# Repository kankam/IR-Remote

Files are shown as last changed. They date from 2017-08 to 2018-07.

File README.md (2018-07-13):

# IR-Remote
This project is to build an IR Remote for Sony Nex 5N Camera. 

An Arduino Pro Mini is used as the Control Unit.
A PCB is designed to mount all the components together.
A plastic case is also designed and can be printed by 3d printers.

The arduino code use the multiCameraControl Libary by Sebastian Setz. Applause to him.

	Project....:  http://sebastian.setz.name/arduino/my-libraries/multi-Camera-IR-Control
	Contact....:  http://Sebastian.Setz.name
	
Theoretically, all camera models include in multiCameraControl Libary (i.e. canon, nikon, olympus, minolta, sony, pentax,) should also be supported by this project with making slight modifications in the Arduino code. 
However, no test has been done except on the Sony Nex 5N Camera.

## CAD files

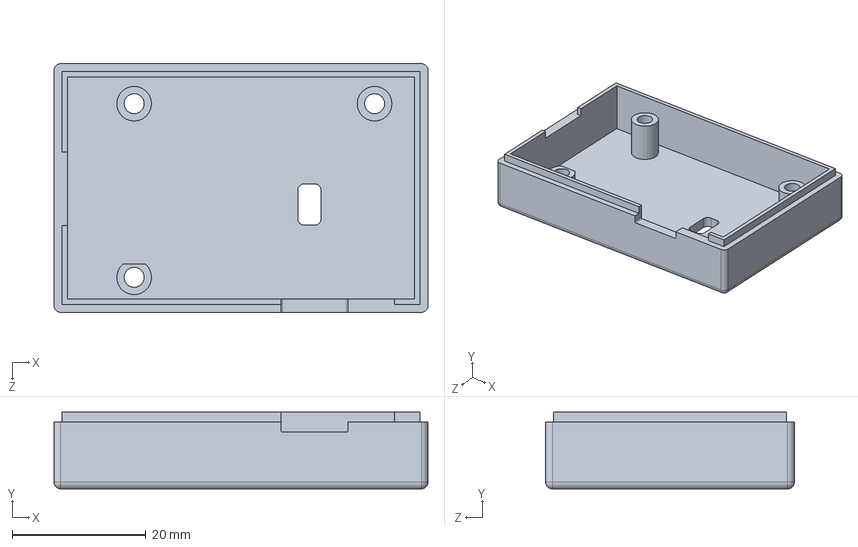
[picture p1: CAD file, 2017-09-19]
SolidWorks/Ir_box_base.SLDPRT
56.0 x 11.5 x 37.2 mm

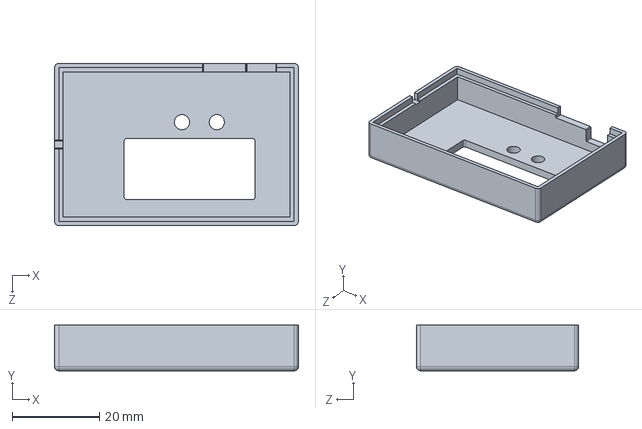
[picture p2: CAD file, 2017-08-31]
SolidWorks/Ir_box_top_without_powerplug.SLDPRT
56.0 x 10.5 x 37.2 mm

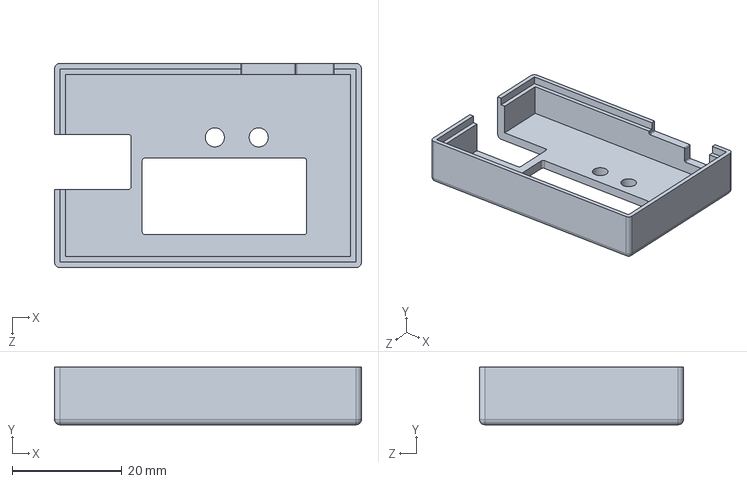
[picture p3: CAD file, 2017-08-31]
SolidWorks/Ir_box_top.SLDPRT
56.0 x 10.5 x 37.2 mm

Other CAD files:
stl/Ir_box_base.STL
stl/Ir_box_top.STL
stl/Ir_box_top_without_powerplug.STL

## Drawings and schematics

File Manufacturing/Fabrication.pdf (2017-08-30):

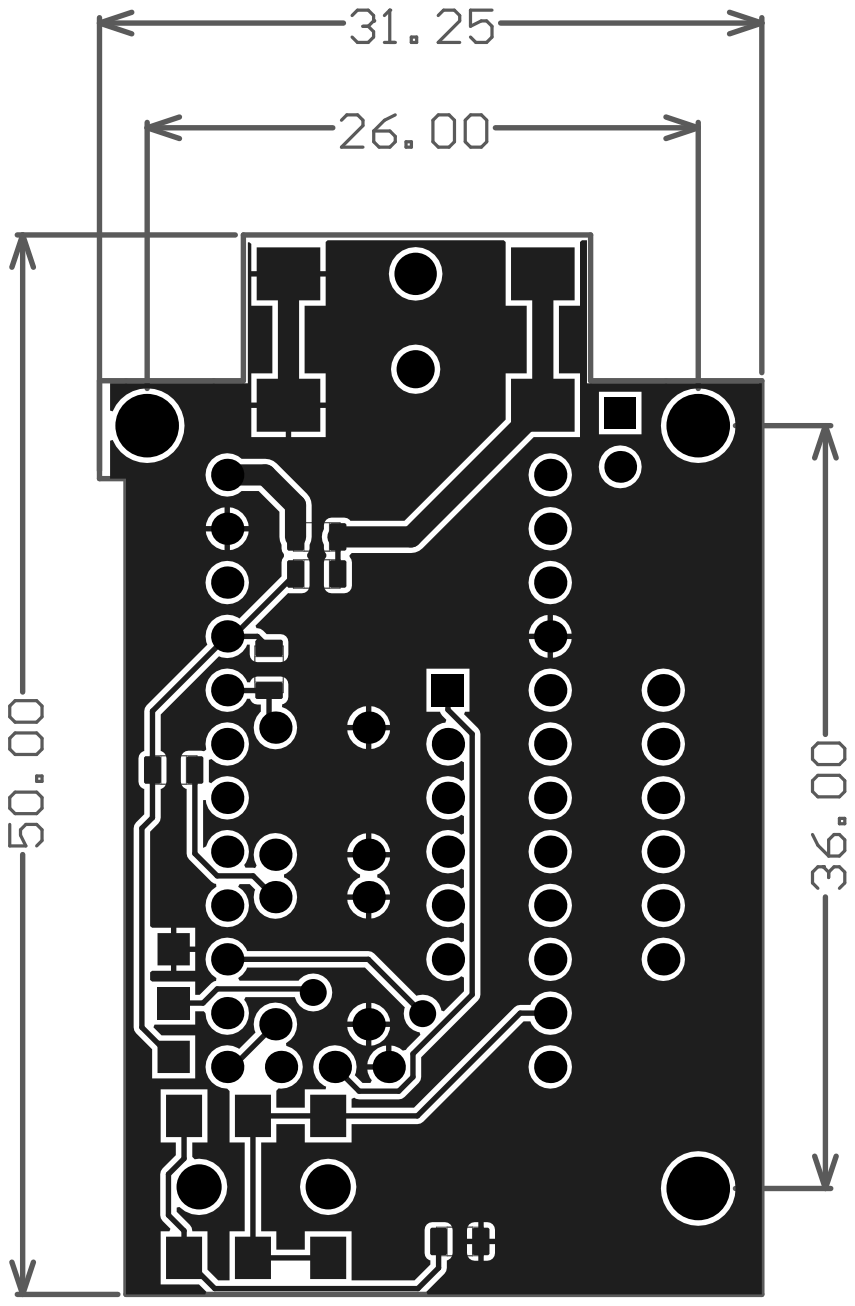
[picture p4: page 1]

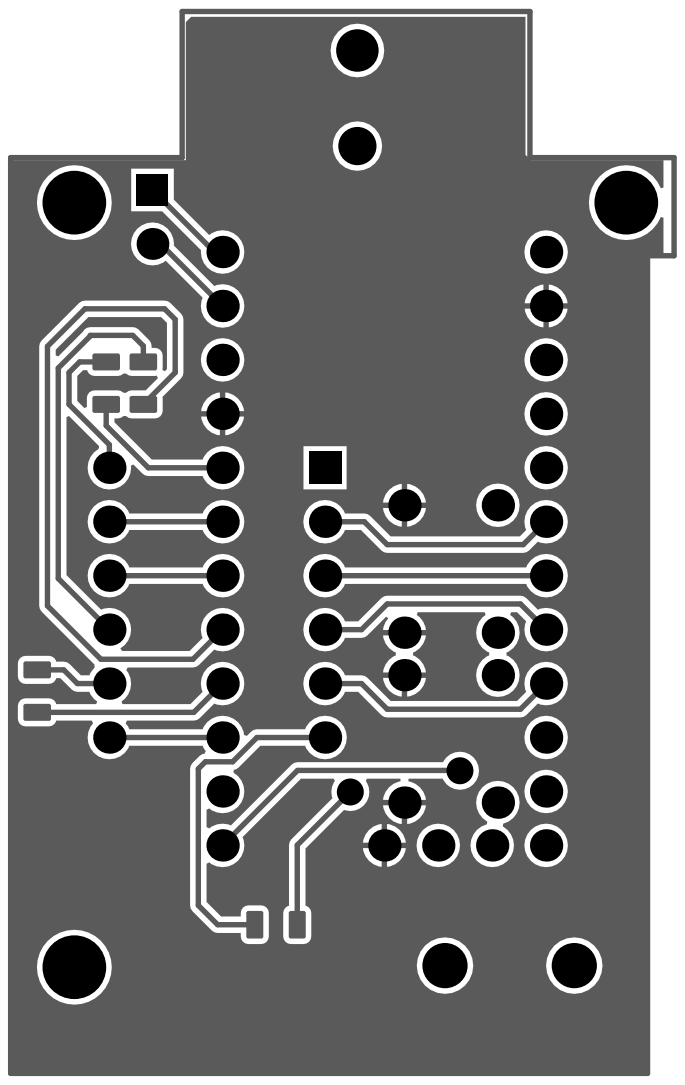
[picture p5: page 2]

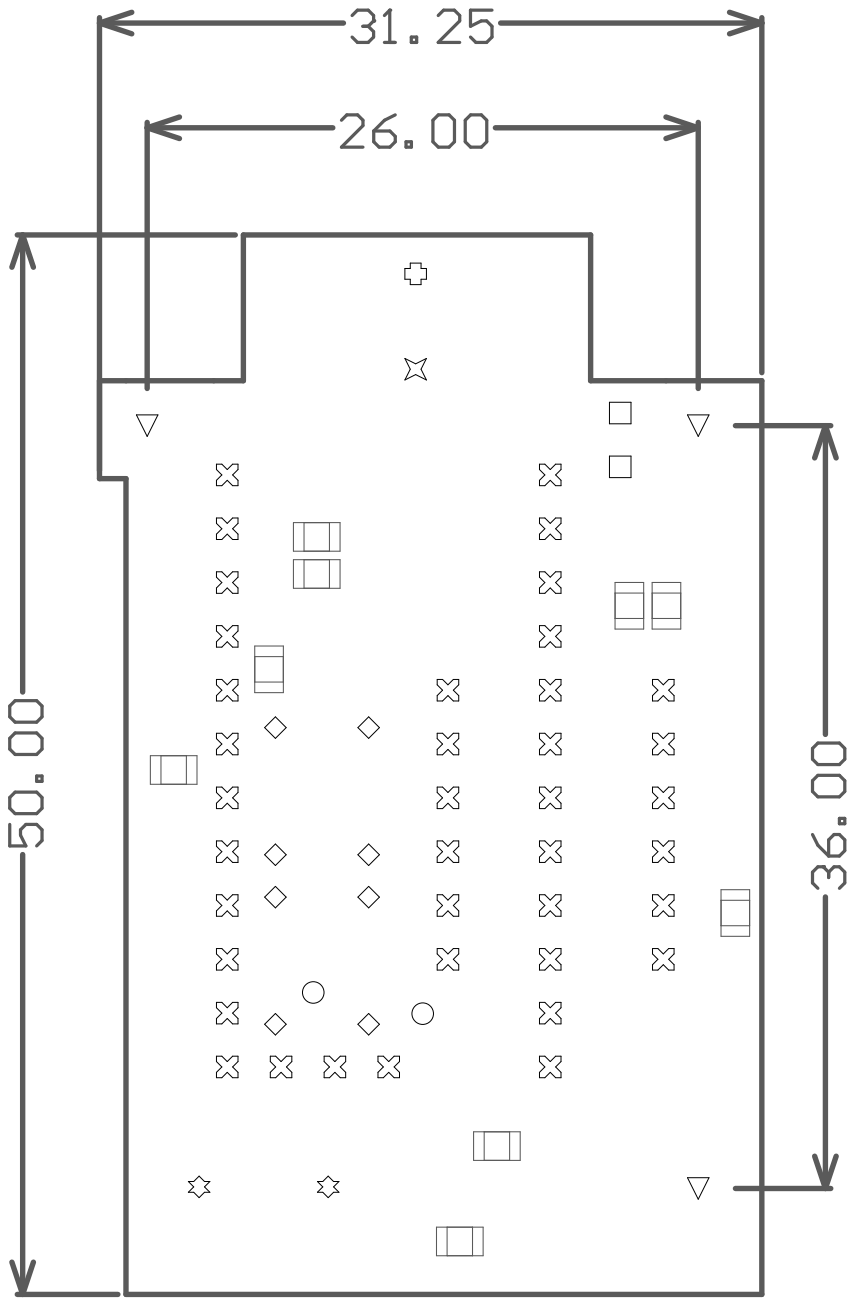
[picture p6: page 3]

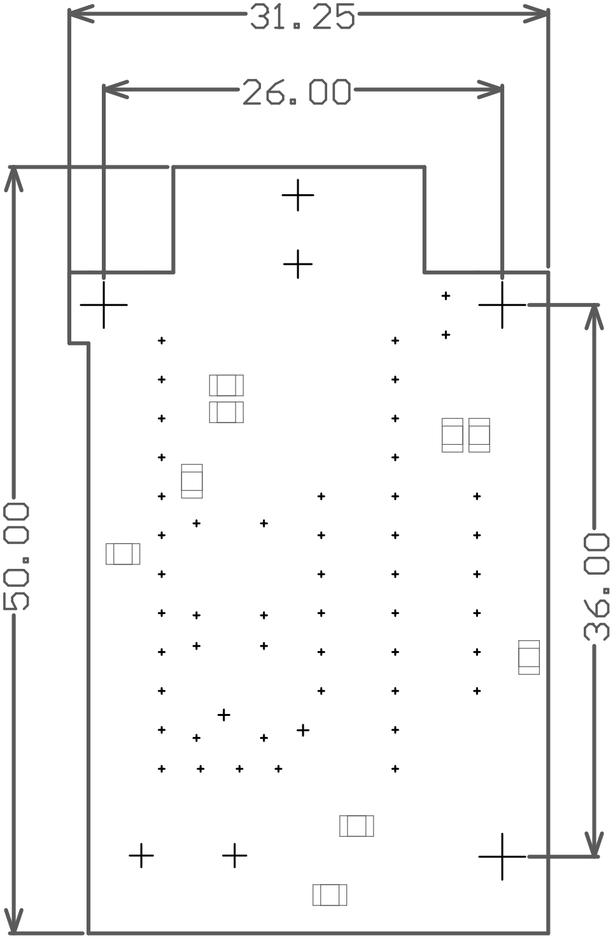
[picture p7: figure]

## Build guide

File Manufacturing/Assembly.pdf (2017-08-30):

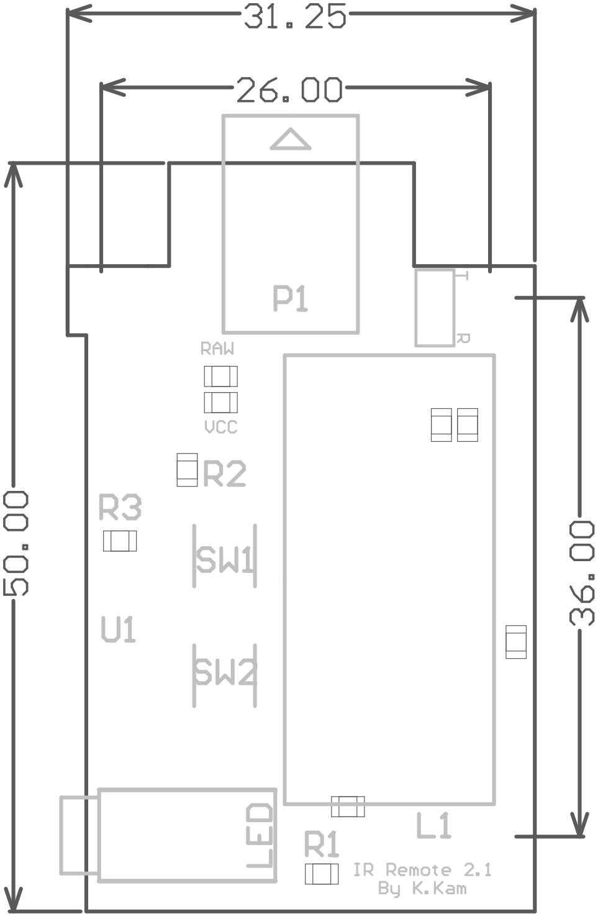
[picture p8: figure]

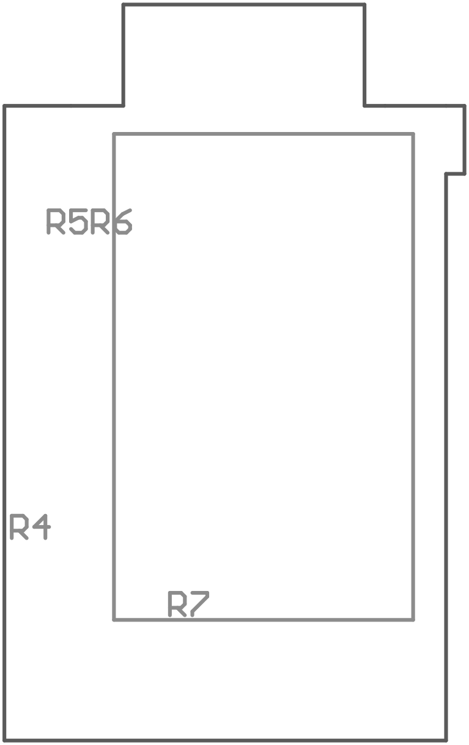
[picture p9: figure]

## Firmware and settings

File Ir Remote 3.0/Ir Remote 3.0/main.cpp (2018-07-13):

/*
 * Ir Remote 3.0.cpp
 *
 * Created: 7/8/2018 11:06:00 PM
 * Author : KanKam
 */ 

#include "main.h"
#include <avr/io.h>
#include <avr/interrupt.h>
#include <util/atomic.h>
#include <util/delay.h>




const char *digPin[4] = {digPin1, digPin2, digPin3, digPin4};
const char *LEDPin[7] = {LEDPinA, LEDPinB, LEDPinC, LEDPinD, LEDPinE, LEDPinF, LEDPinG};
const char *LedPin = irLed;
    
uint16_t counter = 5;    //Default counter is set to 5
uint16_t Digit = 0;      //Display Digit
uint16_t shot = 0;       //Shot count
uint64_t lastCount = 0;  //Time stamp for timing

void digitalWrite(const char *port, bool state){
    //Just like the Arduino,Yeah~!
    int pin =  port[1] - '0';
    if(state == 1)
    {
        switch (port[0]){
            case 'B':
            PORTB |= (1<<pin);
            break;
            case 'C':
            PORTC |= (1<<pin);
            break;
            case 'D':
            PORTD |= (1<<pin);
            break;
            }
        }else{
            switch (port[0]){
                case 'B':
                PORTB &= ~(1<<pin);
                break;
                case 'C':
                PORTC &= ~(1<<pin);
                break;
                case 'D':
                PORTD &= ~(1<<pin);
                break;
                }
        }
}

void shutterNow(void){
    //Ir signal output for Sony camera
    //Source(Author): http://sebastian.setz.name/arduino/my-libraries/multiCameraIrControl (Sebastian Setz)
    bool _seq[] = {1,0,1,1,0,1,0,0,1,0,1,1,1,0,0,0,1,1,1,1}; 
    for (uint8_t j = 0; j < 3; j++) {
        //_freq = 40;
        //pause = 8;
        //high(2320,_freq,_pin);
        for (uint8_t i = 0; i < 145; i++){
            digitalWrite(LedPin,1);
            _delay_us(8);
            digitalWrite(LedPin,0);
            _delay_us(8);
        }
        _delay_us(650);
        for (uint8_t i = 0; i < sizeof(_seq); i++){
            if (_seq[i]==0){
                //high(575,_freq,_pin);
                for (uint8_t i = 0; i < 35; i++){
                    digitalWrite(LedPin,1);
                    _delay_us(8);
                    digitalWrite(LedPin,0);
                    _delay_us(8);
                }
                _delay_us(650);
            }
            else{
                //high(1175,_freq,_pin);
                for (uint8_t i = 0; i < 73; i++){
                    digitalWrite(LedPin,1);
                    _delay_us(8);
                    digitalWrite(LedPin,0);
                    _delay_us(8);
                }
                _delay_us(650);
                _delay_us(650);
            }
        }
        _delay_us(10000);
    }
}
    
void DisplaySingleDigit(uint8_t digit){
    {
        //Display Single Digit on 7 segment display
        //Conditions for displaying segment a
        if(digit!=1 && digit != 4)
        digitalWrite(LEDPin[0],1);
            
        //Conditions for displaying segment b
        if(digit != 5 && digit != 6)
        digitalWrite(LEDPin[1],1);
            
        //Conditions for displaying segment c
        if(digit !=2)
        digitalWrite(LEDPin[2],1);
            
        //Conditions for displaying segment d
        if(digit != 1 && digit !=4 && digit !=7)
        digitalWrite(LEDPin[3],1);
            
        //Conditions for displaying segment e
        if(digit == 2 || digit ==6 || digit == 8 || digit==0)
        digitalWrite(LEDPin[4],1);
            
        //Conditions for displaying segment f
        if(digit != 1 && digit !=2 && digit!=3 && digit !=7)
        digitalWrite(LEDPin[5],1);
        //Conditions for displaying segment g
        if (digit!=0 && digit!=1 && digit !=7)
        digitalWrite(LEDPin[6],1);
    }
}
    
void turnOff(void){
    //Clear 7 segment display
    for(uint8_t i = 0; i < 7; i++){
        digitalWrite(LEDPin[i],0);
    }
}

void displayDigit(uint16_t digit){
    //Display a 4 digit number
    uint16_t fourDigit = digit;
    uint8_t InDigit[4] = {0,0,0,0};
        
    for(int8_t i = 3; i > -1 ; i--) {
        //Store a 4 digit number in a array
        if(fourDigit <= 0){
        InDigit[i] = 0;
        }else {
            InDigit[i] = fourDigit % 10;
            fourDigit /= 10;}
    }
    //7 segment display take turns to display their digit respectively
    for (int b=0; b<4; b++){
        turnOff();
        for(int a=0; a<4; a++){
            digitalWrite(digPin[a],1);
        }
        digitalWrite(digPin[b],0);
        DisplaySingleDigit(InDigit[b]);
        _delay_ms(5);        
    }
}
/*
*avr-millis-function 
*https://github.com/monoclecat/avr-millis-function
*/
volatile unsigned long timer1_millis;

ISR(TIMER1_COMPA_vect)
{
    timer1_millis++;
}

void init_millis(unsigned long f_cpu)
{
    unsigned long ctc_match_overflow;
    
    ctc_match_overflow = ((f_cpu / 1000) / 8); //when timer1 is this value, 1ms has passed
    
    // (Set timer to clear when matching ctc_match_overflow) | (Set clock divisor to 8)
    TCCR1B |= (1 << WGM12) | (1 << CS11);
    
    // high byte first, then low byte
    OCR1AH = (ctc_match_overflow >> 8);
    OCR1AL = ctc_match_overflow;
    
    // Enable the compare match interrupt
    TIMSK1 |= (1 << OCIE1A);
    
    //REMEMBER TO ENABLE GLOBAL INTERRUPTS AFTER THIS WITH sei(); !!!
}

unsigned long millis ()
{
    unsigned long millis_return;
    
    // Ensure this cannot be disrupted
    ATOMIC_BLOCK(ATOMIC_FORCEON) {
        millis_return = timer1_millis;
    }
    return millis_return;
}
/*
*
*/

int main(void)
{
    //Set up GPIO
    //Set them all as output and low
    DDRB = 0xFF;
    PORTB = 0x00;
    DDRC = 0xFF;
    PORTC = 0x00;
    DDRD = 0xFF;
    PORTD = 0x00;
    
    //Set up UP/Down buttons
    DDRC &= ~(1 << DDC2);   //PC2
    PORTC |= (1 << PORTC2); // turn On the Pull-up
    DDRC &= ~(1 << DDC3);   //PC3
    PORTC |= (1 << PORTC3); // turn On the Pull-up
    
    //Set up State Switch
    //Set PC1 (PCINT9 pin) as an input with pull-up enabled
    DDRC &= ~(1 << DDC1);          // Clear the PC1 pin    
    PORTC |= (0 << PORTC1);        // turn On the Pull-down
    PCICR |= (1 << PCIE1);         // set PCIE1 to enable PCMSK1 scan
    PCMSK1 |= (1 << PCINT9);       // set PCINT9 to trigger an interrupt on state change
    
    //run setting mode once if boot with modeSwitch set to 1
    uint16_t delay = 500;
    while (PINC & (1<<PINC1)){        
        displayDigit(counter);
        turnOff();
        if ((PINC & (1<<PINC2))){
            if(counter < 9999){
                counter++;
            }
            if(delay>=5){
                //increase rate when long press
                delay = delay*0.8;
            }
            _delay_ms(delay);
        }
        else if ((PINC & (1<<PINC3))){
            if(counter > 0){
                counter--;
            }
            if(delay>=5){
                //increase rate when long press
                delay = delay*0.8;
            }
            _delay_ms(delay);
            }else{
            delay = 500;
        }
    }
    //Turn on millis counter
    init_millis(F_CPU);
    // turn on interrupts
    sei();
    
    while (1){ //main loop
        /*
        *Note to User:
        *The code is decide for the shutter set in bulb mode.
        *Therefore, counter should be set to shutter - 1 second if shutter time on camera is preset.
        */
        lastCount = millis();
        while (millis() < (lastCount + 3000)){
            displayDigit(shot); //Display shot count, buffer time is set to 3s
        }
        shutterNow();//Bulb mode on camera: Open shutter/ Shutter time is preset: Take a photo

        Digit = counter;
        while( Digit > 0){
            lastCount = millis();
            while (millis() < (lastCount + 1000)){
                displayDigit(Digit);
            }
            Digit--; //Digit -1 for every second
        }
        shutterNow();//Bulb mode on camera: Close shutter/ Shutter time is preset: Do nothing

    }
    return 0;
}


ISR (PCINT1_vect)
{
    //Enter setting mode with interrupt
    uint16_t delay = 500;
    while (PINC & (1<<PINC1)){
        displayDigit(counter);
        turnOff();
        if ((PINC & (1<<PINC2))){
            if(counter < 9999){
                counter++;
            }
            if(delay>=5){
                //increase rate when long press
                delay = delay*0.8;
            }
            _delay_ms(delay);
        }
        else if ((PINC & (1<<PINC3))){
            if(counter > 0){
                counter--;
            }
            if(delay>=5){
                //increase rate when long press
                delay = delay*0.8;
            }
            _delay_ms(delay);
            }else{
            delay = 500;
        }
    } 
    //Exit setting mode
    Digit = counter;
    shot = 0;
    
}

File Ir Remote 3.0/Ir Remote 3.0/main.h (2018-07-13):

/*
 * main.h
 *
 * Created: 7/9/2018 12:36:07 AM
 *  Author: KanKam
 */ 


#ifndef MAIN_H_
#define MAIN_H_

//CPU Frequency 
#define  F_CPU 16000000UL

//7 segment LED
#define LEDPinA     "D7"
#define LEDPinB     "D3"
#define LEDPinC     "D0"
#define LEDPinD     "D1"
#define LEDPinE     "C2"
#define LEDPinF     "D6"
#define LEDPinG     "C5"
#define digPin1     "B0"
#define digPin2     "D5"
#define digPin3     "D4"
#define digPin4     "C4"
//IR LED
#define irLed       "A0"
//Up/Down Button
#define upBtn       "C2"
#define downBtn     "C3"
//Mode Switch
#define modeSwitch  "C1"



#endif /* MAIN_H_ */

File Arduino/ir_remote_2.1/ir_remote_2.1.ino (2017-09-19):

#include <multiCameraIrControl.h>
const int LEDPin[8]={3, 7, 14, 16, 19, 4, 13, 15}; //7segment led pins
const int UP = 10; //For Up Button
const int DOWN = 17; //For Down Button
const int segPin[4]={2, 5, 6, 12}; //7segment dig pin
const int START = 9;  //For start/stop Switch
Sony Nex=8; //For Ir Out
int counter = 5; //Default shutter time 5s
int rate = 200; //Default speed of digit change on Button press
int shot = 0; //Shot count
void setup() {
	  // Set up
	  pinMode(LEDPin[0], OUTPUT);  //A
	  pinMode(LEDPin[1], OUTPUT);  //B
	  pinMode(LEDPin[2], OUTPUT);  //C
	  pinMode(LEDPin[3], OUTPUT);  //D
	  pinMode(LEDPin[4], OUTPUT);  //E
	  pinMode(LEDPin[5], OUTPUT);  //F
	  pinMode(LEDPin[6], OUTPUT);  //G
	  pinMode(LEDPin[7], OUTPUT);  //DP
	  pinMode(UP, INPUT);  //UP
	  pinMode(DOWN, INPUT);  //DOWN
	  pinMode(segPin[0], OUTPUT);  //DIG1
	  pinMode(segPin[1], OUTPUT);  //DIG2
	  pinMode(segPin[2], OUTPUT);  //DIG3
	  pinMode(segPin[3], OUTPUT);  //DIG4
	  pinMode(START, INPUT);  //START/Stop switch for staging
}
void DisplaySingleDigit(int digit)
{
	 //Display Single Digit on 7 segment display
	 //Conditions for displaying segment a
	 if(digit!=1 && digit != 4)
	 digitalWrite(LEDPin[0],HIGH);
	 
	 //Conditions for displaying segment b
	 if(digit != 5 && digit != 6)
	 digitalWrite(LEDPin[1],HIGH);
	 
	 //Conditions for displaying segment c
	 if(digit !=2)
	 digitalWrite(LEDPin[2],HIGH);
	 
	 //Conditions for displaying segment d
	 if(digit != 1 && digit !=4 && digit !=7)
	 digitalWrite(LEDPin[3],HIGH);
	 
	 //Conditions for displaying segment e 
	 if(digit == 2 || digit ==6 || digit == 8 || digit==0)
	 digitalWrite(LEDPin[4],HIGH);
	 
	 //Conditions for displaying segment f
	 if(digit != 1 && digit !=2 && digit!=3 && digit !=7)
	 digitalWrite(LEDPin[5],HIGH);
	  //Conditions for displaying segment g
	 if (digit!=0 && digit!=1 && digit !=7)
	 digitalWrite(LEDPin[6],HIGH);
 }
 void turnOff()
{
	  //Clear 7 segment display
	  digitalWrite(LEDPin[0],LOW);
	  digitalWrite(LEDPin[1],LOW);
	  digitalWrite(LEDPin[2],LOW);
	  digitalWrite(LEDPin[3],LOW);
	  digitalWrite(LEDPin[4],LOW);
	  digitalWrite(LEDPin[5],LOW);
	  digitalWrite(LEDPin[6],LOW);
}


void displayDigit(int digit, int t){
	  //Display a 4 digit number (digit) for (t) ms
	  int InDigit[4]; 
	  unsigned long StartT = millis(); // Record start time of this function
	  unsigned long EndT = StartT + t; //End condition of this function
	  
	  for(int i = 3; i >= 0; i--) {
		//Store a 4 digit number in a array
		  if(digit <= 0){
		  InDigit[i] = 0;}
		  else {InDigit[i] = digit % 10;
		  digit /= 10;}
		  }
	  while(unsigned long NowT = millis() < EndT){
		//7 segment display take turn to display their digit respectively
		for (int b=0; b<4; b++){
		   turnOff();
		  for(int a=0; a<4; a++){
			digitalWrite(segPin[a],HIGH);
			}
			digitalWrite(segPin[b],LOW);
		  DisplaySingleDigit(InDigit[b]);
			delay(5); //Refresh Frequency ~50Hz
		  }
		}
	  } 

void loop() {
int digit = 0; //reset digit display
	  if(digitalRead(START) == LOW){
		 //for setting up the counter
		 displayDigit(counter,5);
		 if (digitalRead(UP) == LOW){
			if(counter < 9999){
			  counter++;
				}
		 displayDigit(counter,rate);
			if(rate>=5){
			  //increase rate when long press
			  rate = rate-5;
				}
			}
		 else if (digitalRead(DOWN) == LOW){
		   if(counter > 0){
			   counter--;
				}
		 displayDigit(counter,rate);
			if(rate>=5){
			  //increase rate when long press
			  rate = rate-5;
				}
		    }
		  else {
			//reset when no button press
			rate=200;
			shot = 0;
			}

	  }
  else if (digitalRead(START) == HIGH){ 
    //shutter bulb mode
	
        //counter should be set to shutter - 1 if shutter time on camera is pre-set
		
      displayDigit(shot,3000); //Display shot count, buffer time is set to 3s
      Nex.shutterNow();//Open shutter when blub mode is chosen on camera / Take a photo
	  
      digit = counter;
         while(digit>0){
          displayDigit(digit,1000);
          digit--;
          }
       Nex.shutterNow();//Close shutter when blub mode is chosen on camera / Do nothing
       shot++;

  }
 }

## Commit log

2017-08-30 Arduino
    Arduino code for the project.
2017-08-30 PCB
    The PCB Design For Ver 2.1
    [Ir Remote 2.0.GBL, Ir Remote 2.0.GBO, Ir Remote 2.0.GBP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]
2017-08-31 STL
    The .stl file for the case.
    [Ir_box_base.STL, Ir_box_top.STL, Ir_box_top_without_powerplug.STL]
2017-08-31 Solidworks
    Solidworks files for the case.
    [Ir_box_base.SLDPRT, Ir_box_top.SLDPRT, Ir_box_top_without_powerplug.SLDPRT]
2017-08-31 Arduino
    Typo fix
2017-09-19 some changes
    [Ir_box_base.SLDPRT, Ir_box_base.STL]
